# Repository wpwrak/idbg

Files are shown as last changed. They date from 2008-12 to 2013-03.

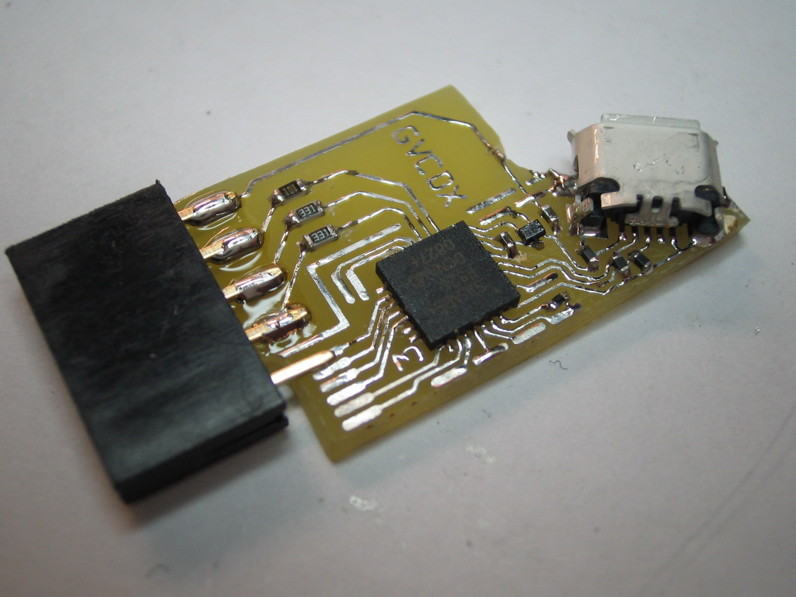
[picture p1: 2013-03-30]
web/idbg-soldered.jpg

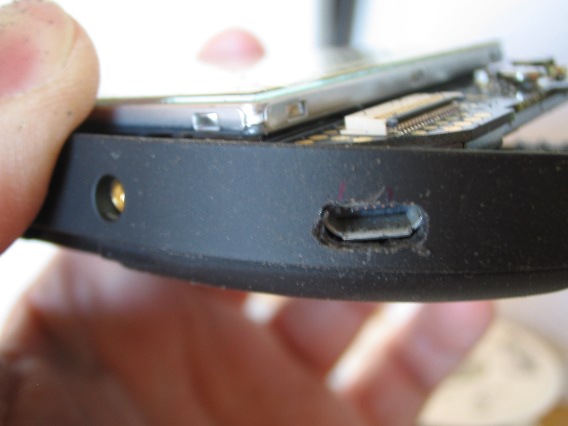
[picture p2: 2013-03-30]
web/hole-trying.jpg

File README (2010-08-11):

Internal Debug Board
====================

Copyright 2008-2010 Werner Almesberger

The files in this package are distributed under the terms of the
GNU General Public License (GPL), either version 2, or (at your
option) any later version.

The full text of the license is included in the file COPYING.GPLv2.

The Internal Debug Board (IDBG) provides the core functionality of the
Openmoko Debug Board in a package small enough that it can be placed
inside the Neo's case (1973 or Freerunner), thus avoiding fragile FPC
connections and making the solution as transportable as the phone
itself.

Overview
--------

IDBG is based on a SiLabs C8051F326 microcontroller. This chip contains
a 8051 core, a voltage regulator, and a full-speed USB device. The only
additional components are a USB receptacle, capacitors to stabilize the
supply voltage, varistors for ESD protection, and an optional dual diode
to separate power sources.

The IDBG board is glued on top of the GPS shield and its Micro USB
receptacle is accessed through a hole roughly opposite the AUX button.

Directory organization
----------------------

fw/		Firmware sources
  boot/		DFU-capable boot loader
  common/	Code shared between boot loader and IDBG
  idbg/		IDBG firmware
  include/	Headers shared between firmware and user space
hw/		Schematics, layout, BOM, and mechanical drawing
f326/		Flash programmer using the C2 protocol
tools/		User-space utilities to perform IDBG operations
  idbg-gpio/	Set and read I/O pins
  idbg-reset/	Reset target (i.e., the Neo) or IDBG
  idbg-con/	Serial console (based on libusb)
  idbg-i2c/	Read/write I2C registers (GTA02)
  idbg-norwp/	Control NOR write protection (GTA02)
  idbg-id/	Identify an IDBG board
  idbg-nnboot/	Control the boot source (Ben)
doc/		Additional documentation material.

Compilation
-----------

Depending on the target, run one of the following commands:

make gta	# for GTA01 or GTA02, any version of IDBG
make ben-v1	# Ben NanoNote, IDBG-Ben version 1
make ben-v2	# Ben NanoNote, IDBG-Ben version 2

Then "make" will build all the rest.

Build process
-------------

See also http://www.almesberger.net/misc/idbg/

- make the PCB
- cut PCB such that IDBG and IPL board are together
- solder the components in this order:
  - U1 (MCU)
  - P1 (USB receptacle)
  - VR1, VR2, VR3 (varistors)
  - C1 (VBUS capacitor)
  - D1 (dual diode, optional)
  - C2 (VDD capacitor)
  - R4 (SDA pull-down)
  - R1, R2, R3 (current limiters on IPL board) (**)
  - Connector on IPL board (*)
- recommended: use a current-limiting lab supply to verify current on
  DEV_VSYS->DEV_GND and VBUS->GND (should be <10mA). Also ensure that
  no current flows between VBUS and VSYS. (**)
- connect a debug v3 board with 0.1" header on J11 (*)
- put the IDBG board on the row with contacts 1 through 9. IDBG GND
  connects to contact 9, contact 1 is left open.
- enable power on the Neo with (**)
  gpio f3=1
  (Note: this only works if the device contains no firmware. With
  firmware, it draws more current than can be supplied this way.)
- compile f326 and copy it to the Neo (requires the arm-linux toolchain)
- identify the device:
  ./f326
  f326 should print a line with 0x0d and a line with 0x01.
- copy the script hw/find-shorts to the Neo
- run the script to perform a boundary scan to detect shorted I/O pins
- recommended: run
  f326 -b rrrrrrrr.rrrrrr
  in a loop while touching I/O pads with a wire that connects through
  1kOhm to GND to test that the traces are good and that the pins are
  properly soldered
- build the firmware in fw/ and copy the boot loader fw/boot/boot.bin
  to the Neo (requires sdcc, package sdcc-nf on Ubuntu 8.10)
- connect USB power to IDBG
- put the boot loader into Flash with
  f326 -p boot.bin
  (This can sometimes fail. Just try again.)
- IDBG should now respond to DFU. Use dfu-util to load the firmware:
  dfu-util -D fw/idbg/idbg.bin
- cut the IPL board off IDBG (the IPL board is destroyed in the process)
- take the Neo's PCB and glue IDBG on the GPS shield
- make a hole for the Micro USB receptacle in the middle part of the
  Neo's case 
- insert the Neo PCB in the case and make sure it fits properly and that
  also the top cover closes
- remove the PCB again
- optional: connect the VSYS pad to the Neo's VSYS
- solder a wire to the GPS can and connect it to IDBG GND
- solder wires to the IDBG I/O pads
- recommended: mark the wires with a "morse" code, see hw/wiring.fig
- recommended: bundle the wires in groups with heat-shrink tubing
- insert the PCB in the case such that the wires pass around the PCB's
  edge to the top
- solder the wires to the corresponding test points around the debug
  board FPC connector
- remove the plastic structure in the top cover that would press on the
  wires
- close the case
- done !

* The use of a debugv3 board is optional. Alternative ways to do the
  initial Flash programming include soldering the IDBG board directly
  to the Neo:

  - connect DEV_GND ("G") to ground
  - DEV_VSYS ("V") goes to EINT3
  - C2CK ("C") to SPI_MISO0
  - C2D ("D") to SPI_CLK0

** If D1 is not placed, the following changes have to be made:

  - do not place R1 either
  - bridge D1 such that VBUS connects directly to the diode's cathode
  - power cannot be supplied from the debug board, so connect USB for
    power

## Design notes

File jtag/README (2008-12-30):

svn checkout -r 1279 svn://svn.berlios.de/openocd/trunk openocd
patch -p0 <openocd.patch
./bootstrap
./configure --enable-bitbang --enable-idbg --enable-ft2232_libftdi

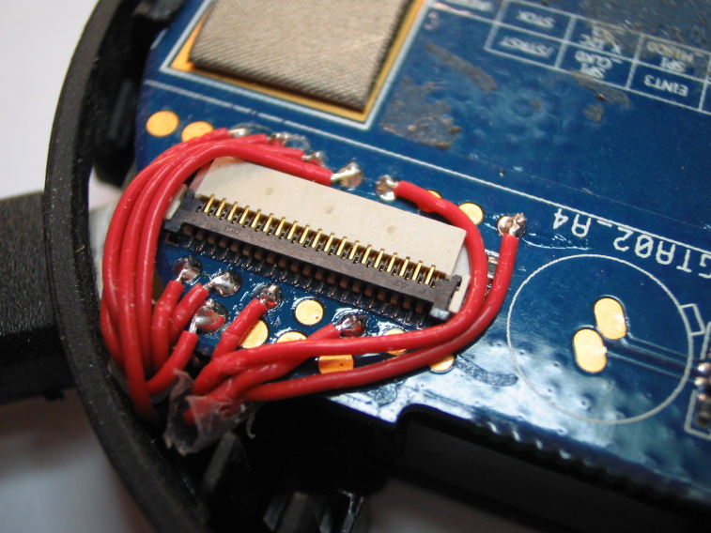
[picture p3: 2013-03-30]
web/idbg-connected.jpg

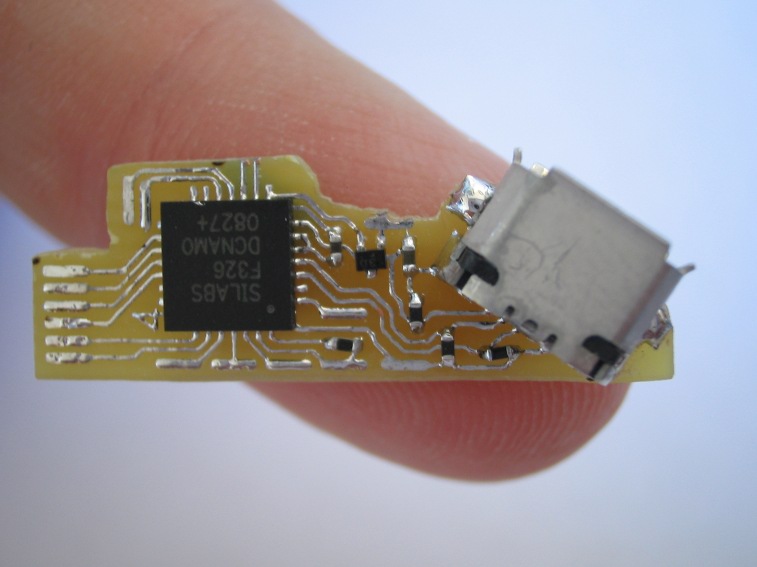
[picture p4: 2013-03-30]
web/pcb-cut.jpg

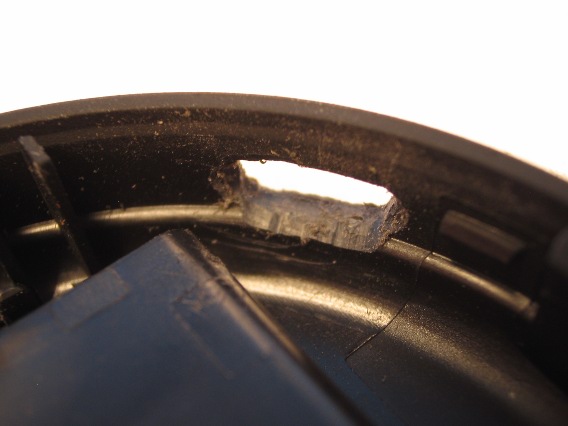
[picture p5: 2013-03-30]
web/hole-inside.jpg

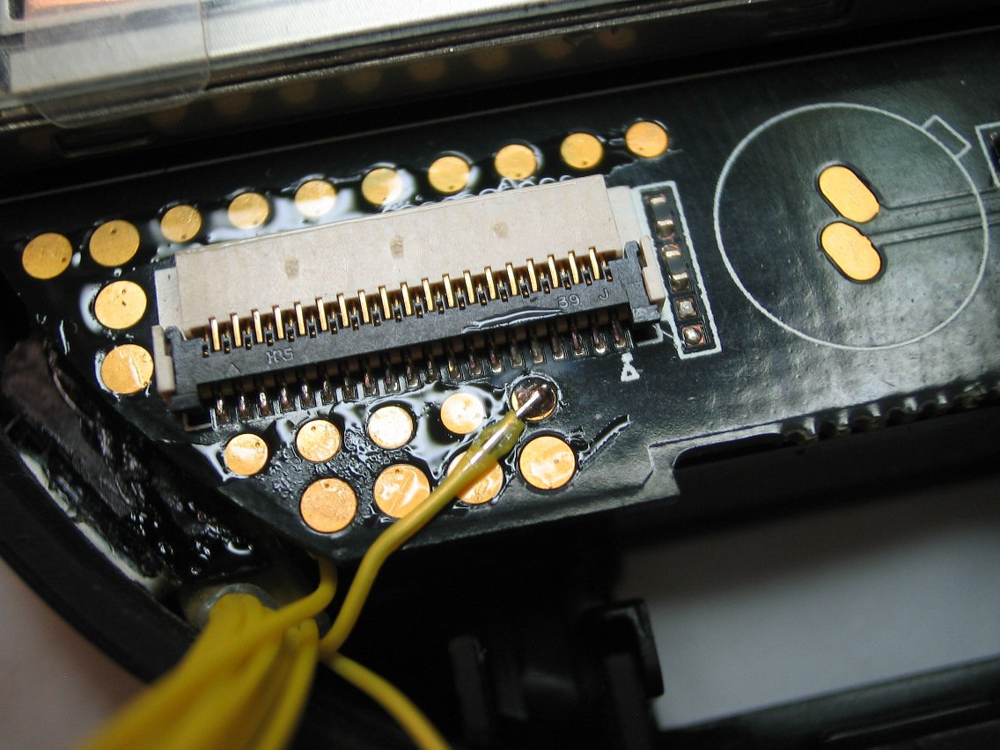
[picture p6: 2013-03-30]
web/ww-first.jpg

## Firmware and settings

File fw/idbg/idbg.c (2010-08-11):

/*
 * idbg/idbg.c - IDBG initialization and main loop
 *
 * Written 2008-2010 by Werner Almesberger
 * Copyright 2008-2010 Werner Almesberger
 *
 * This program is free software; you can redistribute it and/or modify
 * it under the terms of the GNU General Public License as published by
 * the Free Software Foundation; either version 2 of the License, or
 * (at your option) any later version.
 */


#include "regs.h"
#include "uart.h"
#include "io.h"
#include "usb.h"
#include "serial.h"
#include "i2c.h"
#include "idbg/ep0.h"
#include "version.h"


void uart_isr(void) __interrupt(4);


void main(void)
{
#ifdef GTA
	/*
	 * Our pull-up is strong enough to raise nNOR_WP above the threshold.
	 * Besides, we'd burn power if we didn't drive it low.
	 */
	nNOR_WP = 0;
#endif

	/* @@@ since boot and payload may run at different USB speeds, we
	   should also redo the clock init */
	uart_init(24);

	printk("%s #%u\n", build_date, build_number);

	EA = 1;

/*
 * @@@ known issue: USB enumerates fine, but we have to explicitly reset the
 * bus before we can communicate, which is odd. Disconnect (i.e., turning off
 * the pull-up) should be detected within 2-2.5us, so the problem seems to be
 * something else.
 */

	usb_init();
	ep0_init();
	serial_init();
	while (1) {
		usb_poll();
		serial_poll();
#ifdef GTA
		i2c_poll();
#endif
	}
}

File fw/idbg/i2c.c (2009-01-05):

/*
 * idbg/i2c.c - I2C protocol engine
 *
 * Written 2008, 2009 by Werner Almesberger
 * Copyright 2008, 2009 Werner Almesberger
 *
 * This program is free software; you can redistribute it and/or modify
 * it under the terms of the GNU General Public License as published by
 * the Free Software Foundation; either version 2 of the License, or
 * (at your option) any later version.
 */

/*
 * "The I2C-bus and how to use it"
 * http://www.i2c-bus.org/fileadmin/ftp/i2c_bus_specification_1995.pdf
 * "The I2C-bus specification"
 * http://www.semiconductors.philips.com/acrobat_download/literature/9398/39340011.pdf
 */


#include <stdint.h>

#include "regs.h"
#include "uart.h"
#include "io.h"
#include "usb.h"
#include "i2c.h"


static enum state {
	IDLE,
	FAILED,
	START,	/* try to send S */
	SEND,	/* send a byte */
	RECV,	/* receive a byte */
} state = IDLE;

static const uint8_t *wbuf, *wpos, *wend;
static uint8_t *rbuf, *rpos, *rend;
static uint8_t fetched, spos;
static __bit sda;


void i2c_start(uint8_t s, const uint8_t *wdata, uint8_t wlen,
    uint8_t *rdata, uint8_t rlen)
{
	wbuf = wpos = wdata;
	wend = wbuf+wlen;
	rbuf = rpos = rdata;
	rend = rbuf+rlen;
	fetched = 0;
	spos = s;
	state = START;
}


__bit i2c_fetch(struct ep_descr *ep, uint8_t len)
{
	uint8_t *p;
	uint8_t size;

	if (state == FAILED)
		return 0;
	if (state != IDLE) {
		usb_send(ep, NULL, 0, NULL, 0);
	} else {
		size = rend-rbuf;
		if (size)
			p = rbuf+fetched;
		else {
			p = wbuf+2+fetched;
			size = wend-wbuf-2;
		}
		size -= fetched;
		if (size > len)
			size = len;
		usb_send(ep, p, size, NULL, 0);
		fetched += size;
	}
	return 1;
}


#ifndef SIMULATION

static void delay(void)
{
	uint8_t i;

	/*
	 * Minimum loop time is 4 cycles. Maximum clock is 24MHz. We want to
	 * wait at least 5us (for t(LOW)/(tSU;STA), which are both >= 4.7us.
	 */
	for (i = 24*5/4; i; i--)
		__asm nop __endasm;
}

#endif /* !SIMULATION */


void i2c_poll(void)
{
	int8_t i;
	uint8_t data;
	__bit nak;

	switch (state) {
	case IDLE:
	case FAILED:
		break;
	case START:
		if (!I2C_SDA || !I2C_SCL)
			break;
		I2C_SDA = 0;
		delay();
		I2C_SCL = 0;
		state = SEND;
		delay();
		break;
	case SEND:
		if (spos && wpos-wbuf == spos) {
			I2C_SDA = 1;
			delay();
			I2C_SCL = 1;
			delay();
			if (!I2C_SCL)
				break;
			I2C_SDA = 0;
			spos = 0;
			delay();
			I2C_SCL = 0;
			delay();
		}
		sda = *wpos >> 7;
		I2C_SDA = sda;
		delay();
		I2C_SCL = 1;
		if (!I2C_SCL)
			break;
		delay();
		I2C_SCL = 0;
		for (i = 6; i != -1; i--) {
			sda = (*wpos >> i) & 1;
			I2C_SDA = sda;
			delay();
			I2C_SCL = 1;
			delay();
			I2C_SCL = 0;
		}
		wpos++;
		I2C_SDA = 1;
		delay();
		I2C_SCL = 1;
		delay();
		nak = I2C_SDA;
		I2C_SCL = 0;
		I2C_SDA = 0;
		delay();
#ifdef SIMULATION
		nak = 0;
#endif
		if (nak) {
			state = FAILED;
		} else {
			if (wpos != wend)
				break;
			if (rpos != rend) {
				state = RECV;
				break;
			}
			state = IDLE;
		}
		I2C_SCL = 1;
		delay();
		I2C_SDA = 1;
		delay();
		break;
	case RECV:
		I2C_SDA = 1;
		data = 0;
		for (i = 7; i != -1; i--) {
			delay();
			I2C_SCL = 1;
			delay();
			data |= I2C_SDA << i;
			I2C_SCL = 0;
		}
		*rpos++ = data;
		if (rpos != rend)
			I2C_SDA = 0;
		delay();
		I2C_SCL = 1;
		delay();
		I2C_SCL = 0;
		if (rpos != rend)
			break;

		delay();
		I2C_SDA = 0;
		delay();
		I2C_SCL = 1;
		delay();
		I2C_SDA = 1;
		delay();
		state = IDLE;
		break;
	default:
		break;
	}
}

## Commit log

2008-12-06 Initial commit of f326 flasher and some of the hardware files.
    [idbg.brd, idbg.sch]
2008-12-06 On-going development. Now I can get a SETUP packet (get device descriptor) in low-speed mode. For some reason, high-speed mode doesn't seem to work. Cleaned up the build process a little.
2008-12-08 Ongoing development. In order to avoid interfering with USB protocol timing, we use the following general rule for debugging messages:
    - errors and other major events use "printk"
    - general progress messages use "debug"
    - general progress we want to see even when caring about timing uses
    "putchar"
2008-12-10 Changed capture and analysis to support full-speed. dec.py now prints the decoded bitstream as text.
2008-12-10 Fixed the descriptors and did lots more cleanup. The device enumerates now :-)
    [main.c]
2008-12-11 - generalized EP code and introduced EP state - EP0 can now fragment -> low-speed works - revamped version generation such that the build number only increases if we make it to the linking stage
2008-12-12 Support user-specific EP0 handlers.
    - fixed EP0 transfer to the device
    - added user-provided setup handler
    [main.c]
2008-12-12 Make USB DFU protocol actually work.
    - device descriptor was missing the device number
    - used the value instead of the length for download end detection
    - GET/SET_INTERFACE used device request type instead of interface
    - added a bit more stall handling
    - mistook decimal numbers of SET_INTERFACE and SYNCH_FRAME for hex, oops :-)
2008-12-13 Added DFU upload (with small problems).
    - usb_read_word didn't shift the high byte. Amazing that anything worked at all
    with that bug :-)
    - GET_DESCRIPTOR had the content of wValue reversed
    - reduced debugging output
    - high speed started to work again. Use it.
    - moved DFU buffer to XRAM
    - added support for DFU upload
    - the DFU spec doesn't say that block numbers being with zero. So we start the
    block number with the value in the first DFU_DOWNLOAD packet.
    - the last 512 bytes of flash are reserved. Reduce payload size accordingly.
    - signal download errors by setting DFU state and DFU status, not by stalling
    This leaves one known bugs:
    - if sending a multiple of the EP size in full-speed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
2008-12-17 New board designed to sit on the GPS can.
    [idbg.brd, idbg.sch]
2008-12-17 Completed the design and updated peripheral net names.
    [idbg.brd, idbg.sch]
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2008-12-18 Replaced TVS Zener array with varistors.
    - AOZ8205 has a long middle pin that doesn't show up in the data sheet and is
    therefore unsuitable
    - use correct symbol for varistors
    - To free space, removed pads FUTURE1 and FUTURE2
    - added switchable pull resistor on SDA
    - added BOM
    [idbg.brd, idbg.sch]
2008-12-18 Yet another redesign. Turns out V2 still interfered with the top cover.
    This makes the following changes:
    - move USB connector further into edge and rotate it from 26.6 deg (1:2)
    to 33.7 deg (2:3)
    - make board 2mm longer to increase clearance for top lid (with a bit of
    buffer so that we can cut back if necessary)
    - make board a little narrower in top lid conflict area
    - increase clearance from edge wherever possible
    - bring back the pad we lost in the previous version
    [idbg.brd, idbg.sch]
2008-12-19 Pull in outer edge by a whole mm to make more room for top cover.
    [idbg.brd]
2008-12-19 Increased edge clearance of pads close to GPS antenna connector.
    [idbg.brd]
2008-12-20 Starting V4. Move GND trace on IPL board out of harm's way.
    What happened is that it was quite easy to dremel into the trace when
    carelessly cutting the diagonal.
    [idbg.brd]
2008-12-20 Route IPL board's VCC to Vsys pad, so that it can co-exist with USB.
    [idbg.brd, idbg.sch]
2008-12-20 Increase R1 to 100 Ohm, which still seems to be more than sufficient.
    [idbg.sch]
2008-12-20 Major code reorganization to support division into boot loader and payload.
    - boot/Makefile logic now lives in common/Makefile.common
    - payload parameters are now in common/Makefile.system
    - added I/O pin assignment in common/io.h
    - made inclusion of debug, error, and printk configurable through
    subsystem-specific config.h
    - common/regs.h: added REG0CN bits
    - boot/main.c: renamed to boot.c, added USB VBUS as reset source, and added
    primitive jump to payload
    [boot.c, idbg.c, uart.c]
2008-12-20 More rearranging.
    - moved uart.[ch] and usb.[ch] from boot/ to common/
    - adjusted boot/Makefile and idbg/Makefile accordingly
    - new top-level Makefile to build the whole firmware
    - common/Makefile.common: corrected order of phony targets and removed unused
    target "test"
    - boot/dfu.c: we dom't need to include config.h
    [uart.c]
2008-12-21 Oops, USB reset makes us reset too eagerly.
    The USB host resets us when we come up, so taking this as a real reset puts
    us into an endless loop. For now, just revert to not resetting.
    Also,
    - added clock rate selection (for fixed bit rate) to uart_init
    - idbg/Makefile didn't build version.c and version.h was missing
    [boot.c, idbg.c, uart.c]
2008-12-21 We can now jump to the payload directly from DFU.
    This makes development much easier, because it's no longer necessary to
    pull the USB plug to exit DFU mode. Note that the payload may still
    hang (which it currently does), in which case we need a real reset.
    Related changes:
    - don't complain when being sent a DFU_DETACH, just ignore it
    - added user-provided USB reset callback
    - changed product ID of idbg.bin from 0x0001 to 0x0002, for easier
    identification
    - in idbg.c, run usb_init last, for it loops forever ...
    [boot.c, idbg.c]
2008-12-21 Added ISR forwarding from boot loader to payload.
    Other changes:
    - disable interrupts (EA) before jumping to the payload
    - boot/boot.c: don't declare dfu_init locally - use the header file
    - idbg/idbg.c: interrupt test code
2008-12-21 Added stubs for the IDBG EP0 extension protocol.
    Also moved "ep0" into xdata and corrected duplicate declaration.
    [ep0idbg.c, i2c.c, jtag.c]
2008-12-21 Added some JTAG code and did more cleanup.
    Note: this is the first time I play with JTAG at the signal level, so most
    of what I'm doing here may be wrong. We'll see.
    The changes:
    - common/Makefile: generate io-parts.h with the port and bit fields of io.h
    broken down
    - moved polling from usb_init to usb_poll so that caller can do other things
    - common/io.h: removed last remnants of its former life as config.h
    - idbg/jtag.c: put jtag_data into __xdata
    - put some meat into JTAG functions
    [boot.c, idbg.c, jtag.c]
2008-12-21 Exit boot loader when system power comes up.
    We use I2C SDA as an indicator that the system is running under its own
    power. In this case, we jump straight to the payload (unless we're busy
    DFU'ing).
    - export DFU state so that we can prevent boots in the middle of DFU
    - added I2C SDA detection logic to boot loader
    - cleaned up comments explaining boot process
    [boot.c]
2008-12-21 Board V5. Longer, better.
    The main changes are:
    - increase length of board by 0.5mm to create more room for top cover
    - clear 1mm wide zone between MCU and USB connector for top cover
    - increase clearence of components from board edge
    - straighten traces turning under the MCU
    [idbg.brd]
2008-12-22 Since no V4 board was made yet, don't bump the number to V5.
    [idbg.brd]
2008-12-22 Activated the IDBG EP0 protocol.
    - initialize the IDBG EP0 extension
    - introduced new IDBG message IDBG_RESET to force a soft reset
    - disable CONFIG_PRINTK so that we have a quiet console
    [ep0idbg.c, idbg.c]
2008-12-22 Build cleanup.
    - Makefile: make "all" target complain so that we don't trigger uploads by
    accident
    - fw/common/Makefile.common: "make depend" also touches version.c and specify
    that "make version" also builds version.h
    - f326/c2.c: added comment to explain that the pin assignment works for GTA01
    and GTA02
2008-12-23 Wiring diagram for connecting IDBG to the test points on the main PCB.
2008-12-26 Renamed DEV_VBUS to DEV_VSYS.
    [idbg.sch]
2008-12-26 Added README and license, updated the BOM.
    License is GPLv2+, for maximum compatibility. For some items, LGPL or CC
    may be a better choice. That's for future study.
    Added references for "general lab supplies" items to the BOM.
2008-12-27 Preparing boot loader for real life: make it small enough for growing payload.
    - fw/boot/config.h: disabled all diagnostics so that we fit into 4kB
    - fw/boot/dfu.c (flash_write_page): renamed to flash_write_byte because this is
    what it really does
    - fw/boot/dfu.c (my_setup): work-around for SDCC 2.7.0 code-generation bug
    - fw/common/Makefile.system: also second to last page of Flash is sort of
    reserved :-(
    - fw/common/Makefile.system: switched to 4k+11k model
    - fw/common/uart.h: use printf_fast instead of printk
    [ep0idbg.c, uart.c]
2008-12-28 Serial console works !
    - idbg.c: removed old test code for ISRs and bulk out
    - serial.c: use interrupts to keep up at 115kbps
    - serial.h, serial.c: use TX_BUF_SIZE/RX_BUF_SIZE instead of EP1_SIZE
    - serial.c: RI0 and TI0 are bit variables, not bits masks
    - serial.c: enable the receiver
    - idbg.c: call serial_init and serial_poll
2008-12-29 idbg-reset is a utility to reset the target or IDBG itself.
    [idbg-reset.c]
2008-12-29 Added I2C protocol engine (untested).
    - call back EP1 IN on USB reset
    - removed debug output on IDBG_GPIO_UPDATE
    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
    [ep0idbg.c, i2c.c, idbg.c]
2008-12-29 Added I2C simulation and fixed a few bugs in the I2C protocol engine.
    [i2c.c, sim.c]
2008-12-29 I2C fixes: ACK and bit order were wrong.
    [i2c.c, sim.c]
2008-12-29 Added I2C read/write tool. Don't reset USB bus in idbg-gpio.
    [idbg-gpio.c, idbg-i2c.c]
2008-12-29 Track DEV_VBUS -> DEV_VSYS change.
    [idbg.brd]
2008-12-29 Added component and footprint definitions from kicad-parts.
    [idbg.sch]
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2008-12-30 Cleaned up schematics.
    - labeled "FUTURE" net
    - properly grouped JTAG signals
    - grouped IPL board items in a box
    [idbg.brd, idbg.sch]
2008-12-30 Small updates for SDCC 2.8.0.
    It even found a bad pointer conversion :-) Doesn't consider &array to be
    equivalent to just "array".
    [ep0idbg.c, serial.c]
2008-12-30 JTAG works ! It's dreadfully slow, but it does communicate with the target.
    Changes:
    - jtag/README: added --enable-ft2232_libftdi, to stay compatible in the family
    - jtag/openocd.cfg: complete commented-out FT2232 configuration
    - jtag/openocd.patch: we checked the wrong bit for TDO
    [jtag.c]
2008-12-30 idbg-gpio.c didn't IDBG_GPIO_UPDATE before setting, causing junk to be written.
    [idbg-gpio.c]
2008-12-30 FUTURE and SCL have swapped places.
    This way, we can use an interrupt to sample SDA, which may be useful for
    building an I2C snooper. (Not entirely sure if this is enough, but it's
    better than nothing.)
    - fw/common/usb.c: avoid compiler warning about confused code generation
    internals
    - web/index.html: update for JTAG, I2C, and compiler warnings
    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
    [idbg.brd, idbg.sch]
2008-12-31 Updated wiring and layout after test build.
    - wiring.fig: test points nWAIT and GPA15 don't exist on all models
    - wiring.fig: warn that nNOR_WP breaks the sequence
    - idbg.brd: increase clearance of I2C_SCL from D+/D-
    [idbg.brd]
2008-12-31 Update documentation.
    - hw/wiring.fig: mention why we warn
    - web/index.html: V4 test build with thin PCB and wire-wrap has been done
2009-01-03 Added JTAG acceleration.
    - fw/idbg/: renamed request IDBG_JTAG_SEND to IDBG_JTAG_SCAN
    - fw/idbg/:added IDBG_JTAG_MOVE, the TMS equivalent to IDBG_JTAG_SCAN
    - fw/idbg/jtag.c: don't reset the TAP on attach/detach
    - openocd/src/jtag/idbg.c: exit on any communication failure, so that we don't
    busy-loop on disconnect
    - fw/idbg/: wIndex in IDBG_JTAG_SCAN now indicates if this is the last part of
    a scan
    - fw/idbg/: fixed lots of bit counting bugs related to JTAG
    - fw/idbg/jtag.c (jtag_scan): simplified shift logic
    - fw/idbg/jtag.c (jtag_scan): added end-of-shift state transition logic
    - fw/idbg/ep0idbg.c (my_setup): worked around various code generation bugs in
    SDCC 2.8.0
    - fw/idbg/serial.c: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
    [ep0idbg.c, jtag.c, serial.c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]
2009-01-05 I2C access works.
    - fw/idbg/: rewrote I2C protocol engine and its interface
    - fw/idbg/test/i2c/sim.c: updated simulator for new API
    - tools/idbg-i2c/idbg-i2c.c (main): used the wrong argument for the value to
    write
    - tools/idbg-i2c/idbg-i2c.c (main): reduce delay from 1s to 100ms
    - tools/idbg-con/idbg-con.c (main): reduce delay from 1s to 100ms
    [ep0idbg.c, i2c.c, idbg-i2c.c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]
2009-01-06 Renamed GSM_EN to nGSM_EN.
    We actually have this wrong in most of our schematics, i.e., debugv3 and
    GTA01. GTA02 is good, though.
    [idbg.brd, idbg.sch]
2009-01-06 GPIO data register setting logic was broken. Redesigned it.
    - fw/idbg/ep.c: removed IDBG_GPIO_UPDATE and shadow registers
    - fw/idbg/ep.c: on IDBG_GPIO_DATA_SET, set/clear each bit individually
    - tools/idbg-gpio/idbg-gpio.c: removed IDBG_GPIO_UPDATE
    - tools/idbg-gpio/idbg-gpio.c: dump all GPIOs if invoked without argument
    - tools/idbg-gpio/idbg-gpio.c: removed now redundant option -a
    - tools/Makefile.common: "install" depends on the program we're installing
    [ep0.c, idbg-gpio.c]
2009-01-07 Only "nooverlay" functions that need it.
    - fw/idbg/serial.c: added "#pragma save" and "#pragma restore" to allow
    overlaying for functions that are not called from the interrupt handler.
    (Doesn't actually make a difference in terms of memory use.)
    [serial.c]
2009-01-07 The serial console no longer loses entire URBs.
    It turned out that the problem wasn't in IDBG but in idbg-con: when a
    URB is cancelled because we time out and just at that moment the data
    finally arrives, the data is lost.
    Rewrote idbg-con to use a thread that just sits there and blocks.
2009-01-07 Make ~. in idbg-con work again.
    USBDEVFS_BULK is uninterruptible, so it hangs the exit(2) on ~.
    In order to extricate ourselves from USBDEVFS_BULK, we just reset the
    USB device. What a messy interface :-(
2009-01-08 Show alternative wiring with wire-wrap wire.
    - web/: added alternative wiring using wire-wrap wires
    - web/index.html: clarify that debug board co-existence does indeed work
    - web/index.html: capitalize "Morse" code
    - web/Makefile: added copyright notice
2009-02-08 Update the Web page with latest status and details on PMU control:
    - if USB power is absent, leakage into GPIOs is only about 10 nA
    - added description for switching VSYS to limit inrush current
2009-02-08 Forgot to remove leakage current check from to do list.
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2010-06-30 Added a Ben NanoNote variant of IDBG. Untested so far.
    zx62m-b-5p.fpd is the USB connector's footprint drawn with fped, from
    http://svn.openmoko.org/trunk/eda/fped/
    [idbg-ben.brd, idbg-ben.sch]
2010-06-30 Another missing commit: move open_usb from idbg-con.c and idbg-i2c.c to common library. Add option -d to idbg-con and idbg-i2c to set USB vendor/product ID.
    [idbg-i2c.c]
2010-07-04 Switched UART over to the pins shared with JTAG, to avoid conflict with the keyboard. This means that also the DFU detection logic has to change. We now probe +V3.3 directly. This makes then Ben vari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
    [idbg-ben.brd, idbg-ben.sch]
2010-07-04 For idbg-ben, we reuse C2D (P3_0) to connect to reset. Added P3_0 support for IDBG_GPIO_DATA_SET. idbg-reset now toggles the reset pin for GTA01/02 and for Ben.
    [ep0.c, idbg-reset.c]
2010-07-05 Added dual use of P3_0 as C2D and RESETP_N to schematics and layout. (Layout does not change.)
    [idbg-ben.brd, idbg-ben.sch]
2010-07-05 Added README.NANONOTE with build and usage instructions. Added side wall of the Ben's case to idbg-ben-place.fig
2010-07-15 Oops, R3 on the Ben is 1 kR, not 100 kR. The schematics were right but the BOM had it wrong.
2010-08-02 Upgraded idbg-ben to revision 2. This revision uses a timeout to switch from the boot loader to the application and therefore no longer needs to tap into +V3.3.
    - idbg-ben.sch, idbg-ben.brd: removed host voltage detection on P0.1 and P0.2,
    with R3 and pad P3 (+V3_3/TP9)
    - idbg-ben.sch, idbg-ben.brd: to straighten routing of cables, moved RESETP_N
    from P3.0 to P0.1, and BOOT_SEL1 from P0.2 to P3.0
    - idbg-ben.sch, idbg-ben.brd: added a pad (P3) to access VBUS for initial
    programming
    - idbg-ben.brd: increased clearance from 6 mil to 7 mil and adjusted routing
    - idbg-ben.brd: rotated P4 through P6 by 45 degrees, for easier access
    - idbg-ben.brd: rotated P8 to straighten routing of cable
    -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
    [idbg-ben.brd, idbg-ben.sch]
2010-08-02 idbg-ben.sch: corrected "BOOT_SEL" to "BOOT_SEL1"
    [idbg-ben.sch]
2010-08-03 Added different build targets for firmware:
    - fw/Makefile: set build target (in file .target) by running "make gta",
    "make ben-v1", or "make ben-v2". Remove the target setting with "make
    spotless"
    - common/Makefile.common: pass target in CFLAGS
    - common/Makefile.common: make all compilations and the dependencies depend on
    ../.target
    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
2010-08-03 First, a bug from the previous commit:
    - fw/common/Makefile.common (depend): don't depend on .depend
    Make UART speed a compile-time variable:
    - fw/common/uart.c (uart_init): introduce defines UART_115200_BPS and
    (UART_57600_BPS to set UART clock dividier accordingly
    - fw/common/Makefile.system: set DEFINE_UART_SPEED to UART_115200_BPS or
    UART_57600_BPS, depending on target
    - fw/boot/Makefile, fw/idbg/Makefile: pass DEFINE_UART_SPEED when compiling
    uart.c
    - fw/common/Makefile.common: pass a dummy UART speed when generating
    dependencies
    [uart.c]
2010-08-03 Removed kicad-nxn.pl from the repository since it's basically a script for my local setup. (And not of much relevance lately.)
2010-08-03 Fixed build failure due to overly paranoid checks in shared includes. Updated USB vendor ID use in tools.
    - fw/include/idbg/ep0.h, fw/include/idbg/usb-ids.h: if including in a tool, we
    don't know what the target is (and we may even support multiple targets), so
    it's not an error if the target isn't set
    - tools/lib/usb.c (open_usb): search for USB_VENDOR_OPENMOKO and
    USB_VENDOR_QI_HW by default
    - tools/idbg-gpio/Makefile, tools/idbg-gpio/idbg-gpio.c (open_usb): removed
    local version of open_usb; use the one in lib/usb.c instead
    - tools/idbg-reset/Makefile, tools/idbg-reset/idbg-reset.c (open_usb): removed
    local version of open_usb; use the one in lib/usb.c instead
    [idbg-gpio.c, idbg-reset.c]
2010-08-10 hw/idbg-ben.sch: correc label of BOOT_SEL1 and indicate to which pin it goes.
    [idbg-ben.sch]
2010-08-11 Quick and dirty removal of GTA-specific firmware functionality on Ben versions.
    - fw/idbg/Makefile, fw/idbg/ep0.c (do_jtag_scan, my_setup), fw/idbg/idbg.c
    (main): include JTAG and I2C only on GTA
    - fw/idbg/idbg.c (main): use GTA-specific nNOR_WP only on GTA
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2010-08-11 - tools/idbg-reset//idbg-reset.c (usage, main): changed option -d to -i, to allow for future addition of a -d vendor:product option.
    [idbg-reset.c]
2010-08-11 tools/idbg-reset/Makefile, tools/idbg-reset/idbg-reset.c (reset_target): idbg-reset now identifies the target and sends the reset pulse on the reset pin of the target (instead of sending a pulse on a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
    [idbg-reset.c]
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
